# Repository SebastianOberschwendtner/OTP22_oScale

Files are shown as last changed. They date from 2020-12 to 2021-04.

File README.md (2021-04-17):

Card
# OTP22_oScale







Open Source Scale for Brewing Espresso.

>More information can be found in the *beautiful* [wiki](https://github.com/knuffel-v2/OTP22_oScale/wiki/home).

>:construction: The **schematic** and **PCB** are designed with *CircuitMaker*. The project can be found [here](https://circuitmaker.com/Projects/Details/SebastianOberschwendtner/OTP-22oScale).

## Software Framework







## Branches
|Name|Status|Description|
|---|---|---|
|**main**|`active`| Main branch for developing with VSCode|
|**unittest**|`stale`| Branch to test unit test framework and github actions.|
 
## Technical Data

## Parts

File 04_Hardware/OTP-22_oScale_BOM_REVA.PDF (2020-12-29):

Designator | Comment | Quantity
C1, C2, C3, C4 | 22 pF | 4
C5, C6, C9, C10, C11, C12 | 100 nF | 6
C7 | 100 µF | 1
C8, C14, C16 | 1.0 µF | 3
C13, C15 | 2.2 µF | 2
D1 | 1N4148 | 1
J1 | Battery Connector | 1
K1 | Display | 1
K2 | Programming Port | 1
Q1, Q3 | IRLML2502 | 2
Q2 | IRLML6401 | 1
R1, R12, R17, R19 | 22 kO | 4
R2, R16, R20 | 4.7 kO | 3
R3, R4 | 32 kO | 2
R5, R6, R7, R18, R21, R24 | 1 kO | 6
R8, R9, R10 | 100 kO | 3
R11 | 180 O | 1
R13, R14, R25 | 10 kO | 3
R15 | 100 O | 1
R22 | 57 O | 1
R23 | Offset | 1
SW1, SW2, SW3, SW4 | 430186050716 | 4
U1 | ATmega8L-8PU | 1
U2, U3 | LT1013D | 2
U4 | Texas Instruments ADS7822P | 1
U5 | AD580SH | 1
U6 | LF33CDT-TR | 1
U7 | LM7805 | 1
X1 | 8.0 MHz | 1
X2 | Load Cell Connector | 1

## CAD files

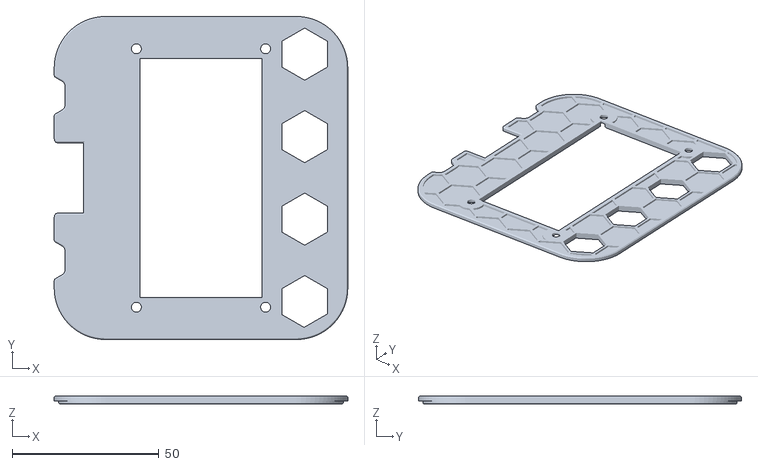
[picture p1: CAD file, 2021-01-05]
04_Hardware/OTP-22_Case_Top_v002.stl
100.0 x 110.0 x 2.80

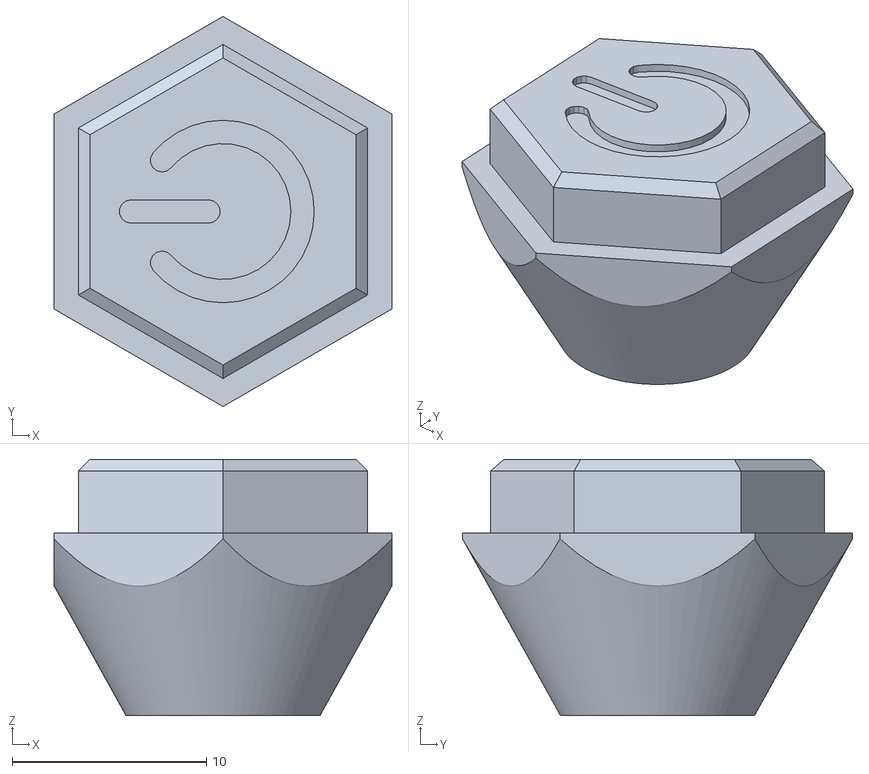
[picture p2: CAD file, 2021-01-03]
04_Hardware/OTP-22_Key_0_v002.stl
17.4 x 20.1 x 13.2

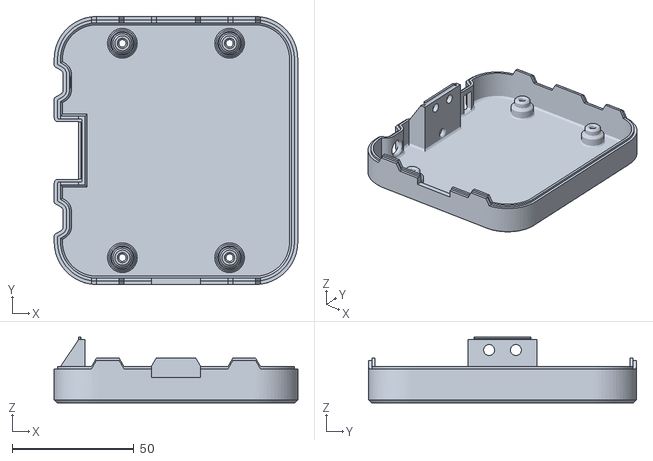
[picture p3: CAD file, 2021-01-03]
04_Hardware/OTP-22_Case_Bottom_v001.stl
100.0 x 110.0 x 26.9

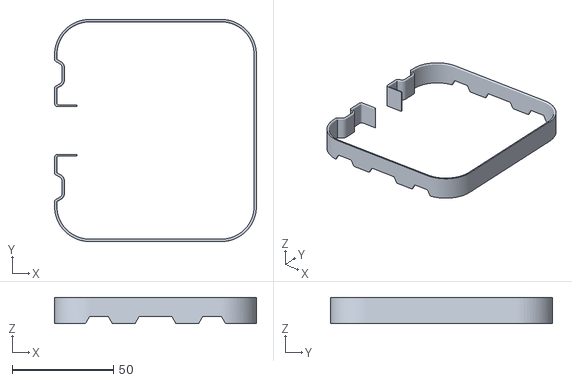
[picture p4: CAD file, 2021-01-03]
04_Hardware/OTP-22_Case_TopFrame_v001.stl
100.0 x 110.0 x 12.9

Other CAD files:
04_Hardware/OTP-22_Key_2_v001.stl
04_Hardware/OTP-22_Key_1_v001.stl
04_Hardware/OTP-22_Key_3_v001.stl
04_Hardware/OTP-22_Case_Top_v001.stl
04_Hardware/OTP-22_Key_0_v001.stl

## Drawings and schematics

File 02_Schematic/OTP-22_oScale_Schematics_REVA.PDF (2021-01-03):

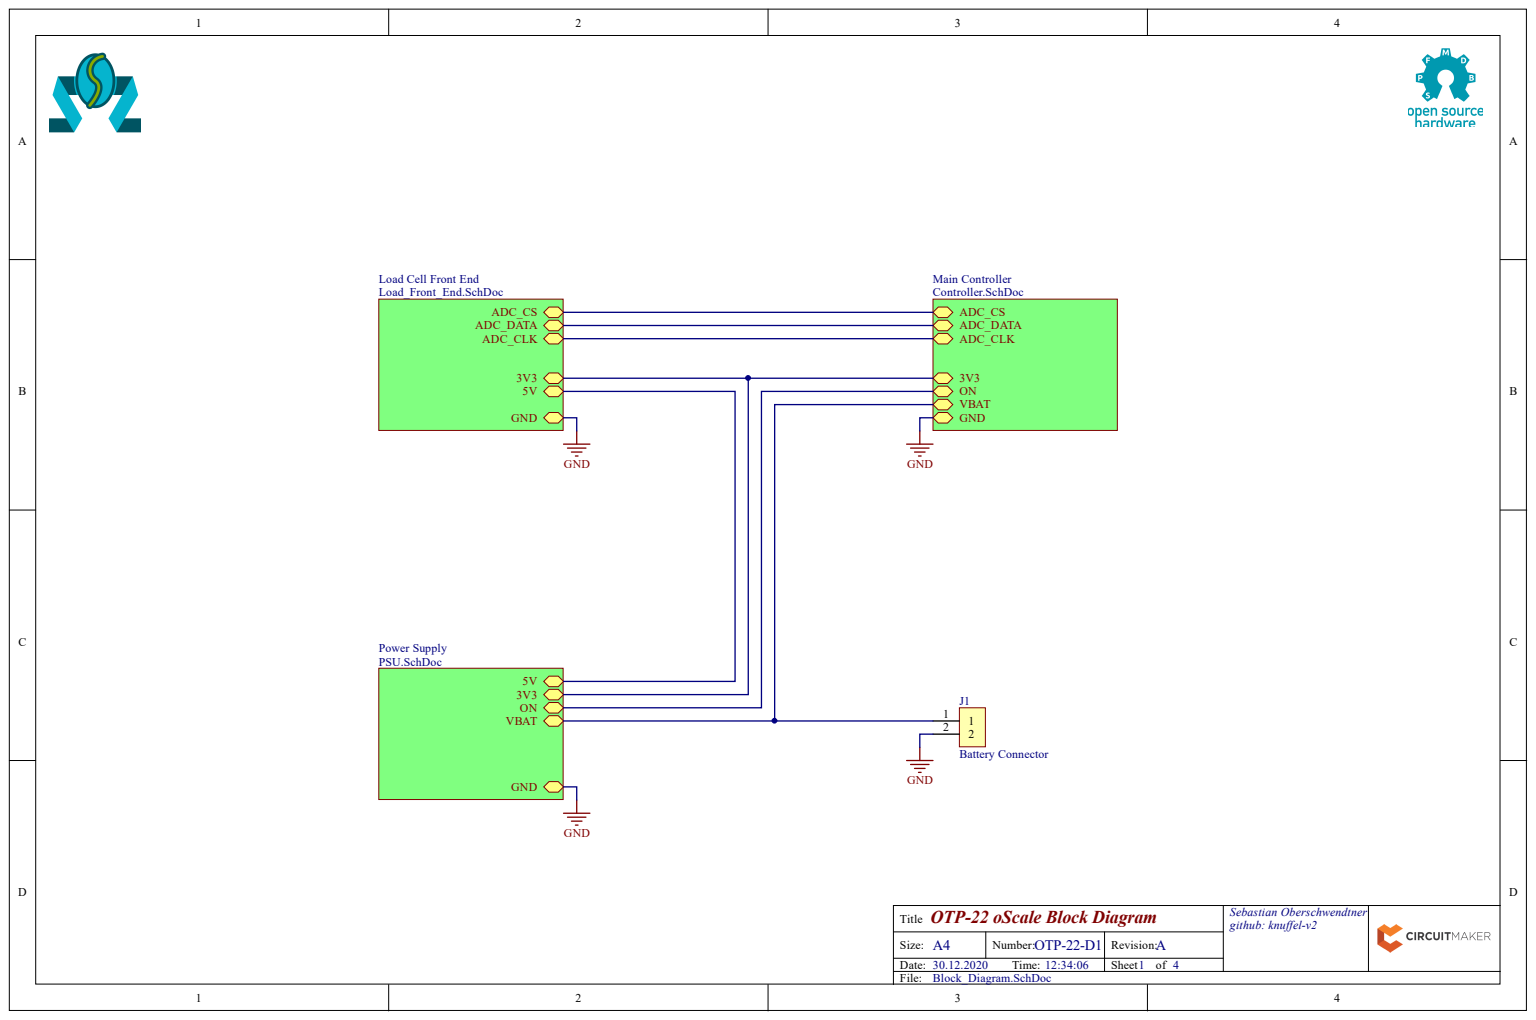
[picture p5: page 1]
Main Controller; Power Supply; Battery Connector

Load Cell Front End
Load_Front_End.SchDoc

OTP-22 oScale Block Diagram Title | Sebastian Oberschwendtner github: knuffel-v2

Size: A4 | Number: OTP-22-D1 | Revision: A
Date: 30.12.2020 Time: 12:34:06 | | Sheet of

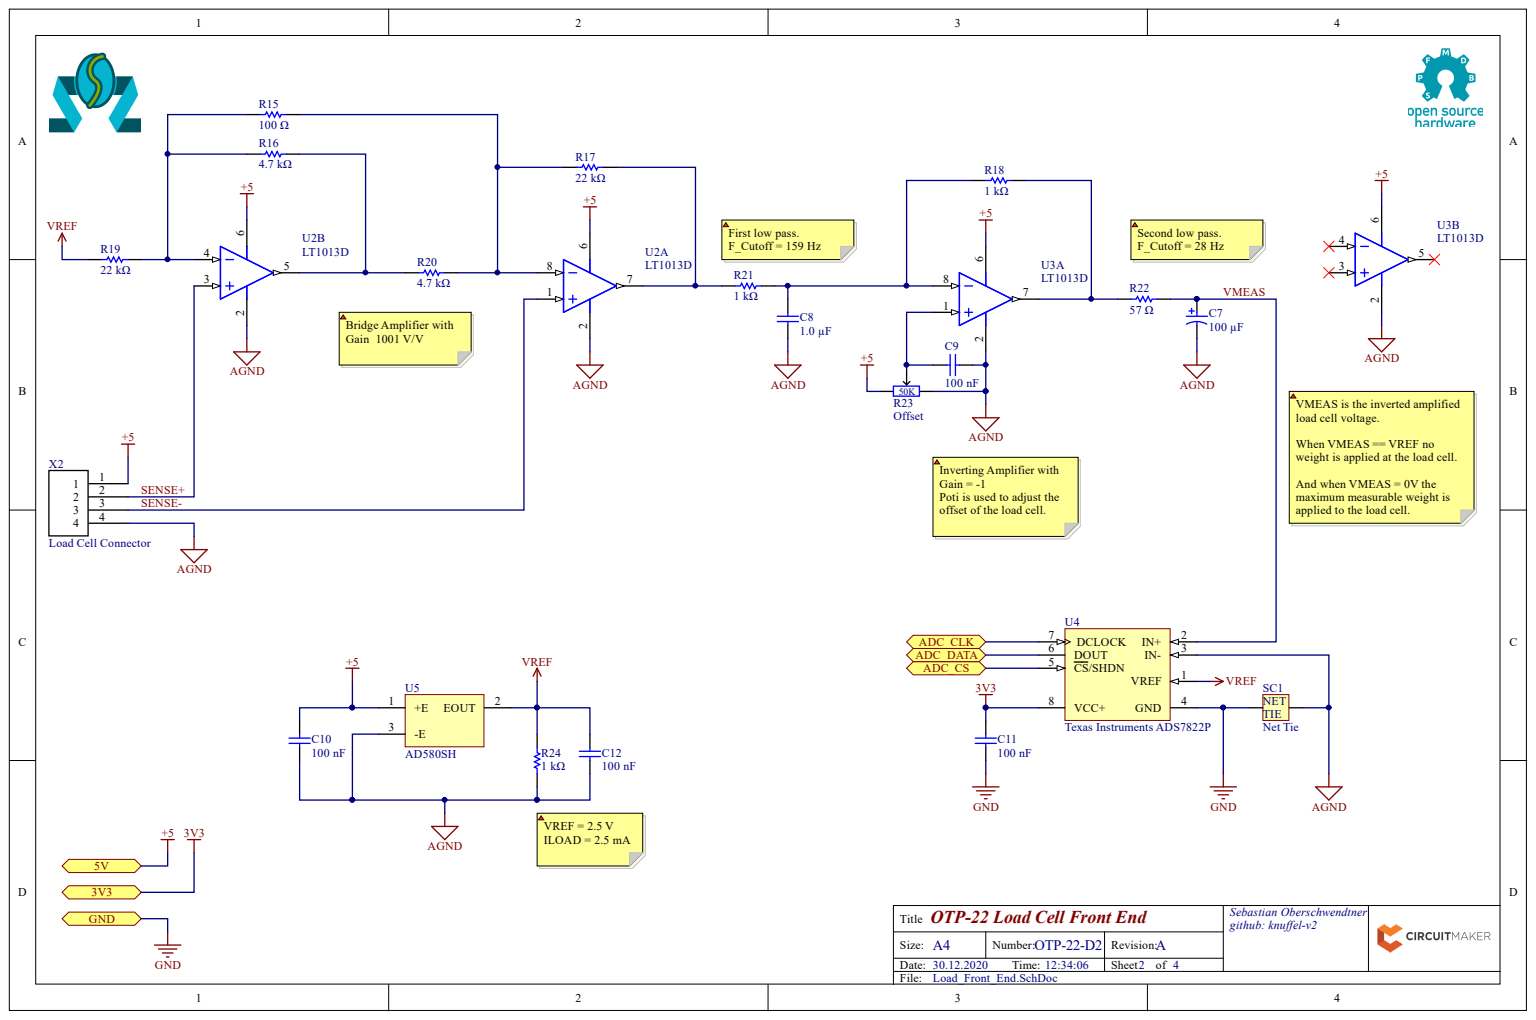
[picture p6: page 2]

VMEAS is the inverted amplified
load cell voltage.

When VMEAS == VREF no
weight is applied at the load cell.

Inverting Amplifier with
Gain = -1
Poti is used to adjust the
offset of the load cell.

And when VMEAS = 0V the
maximum measurable weight is
applied to the load cell.

OTP-22 Load Cell Front End Title | Sebastian Oberschwendtner github: knuffel-v2

Size: A4 | Number: OTP-22-D2 | Revision: A

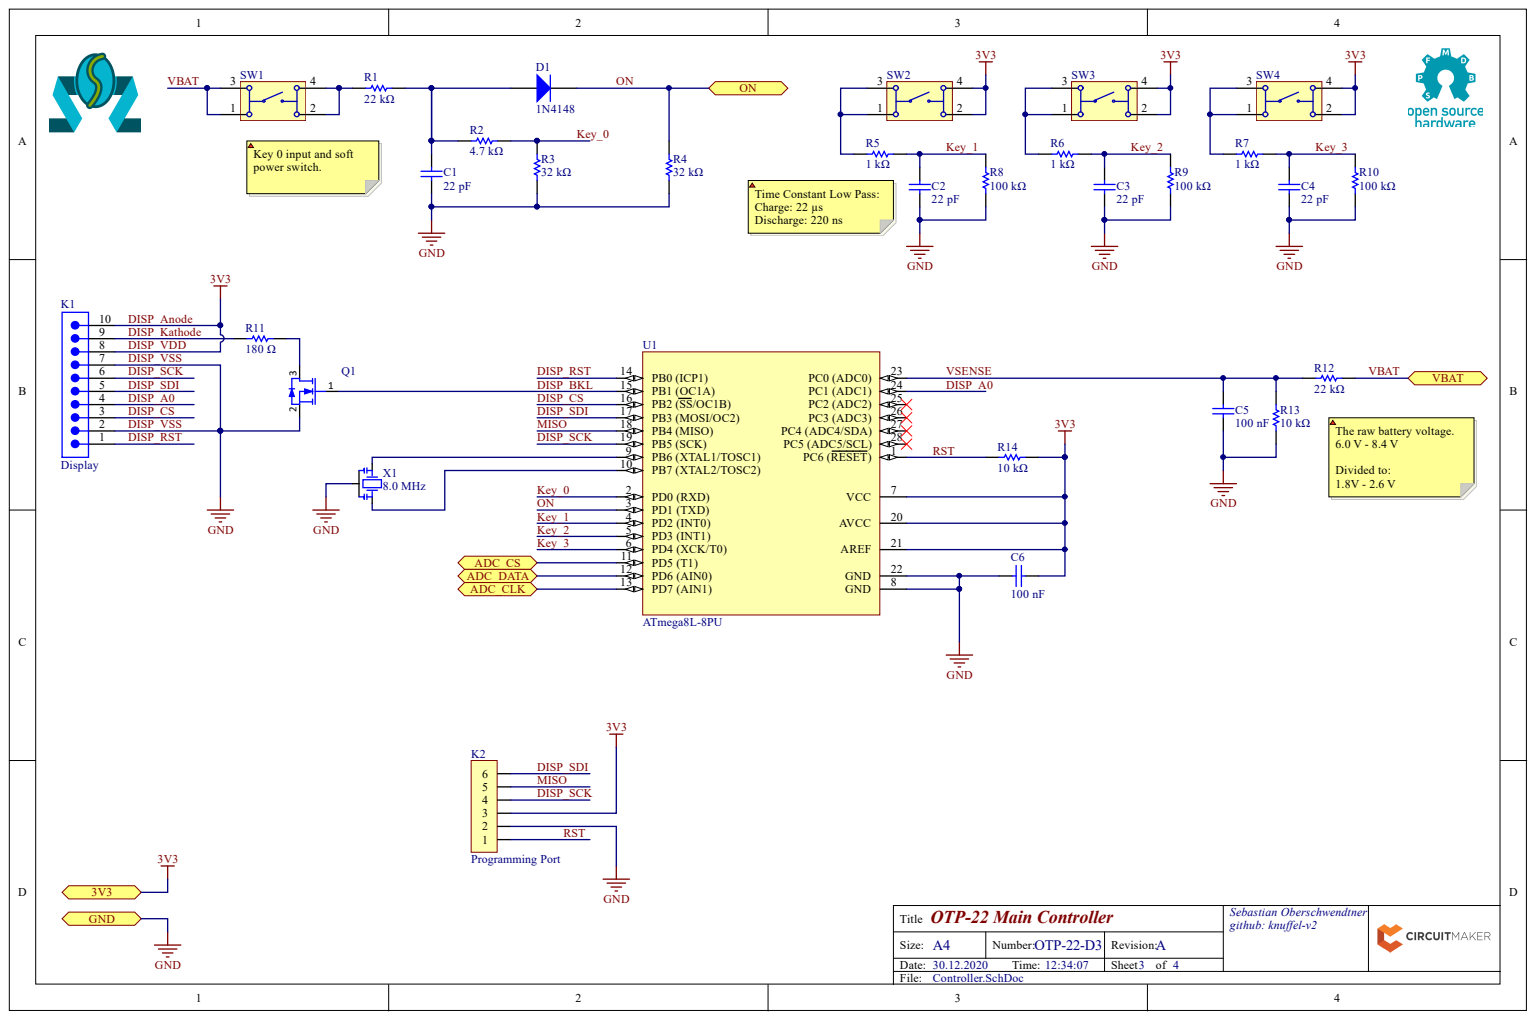
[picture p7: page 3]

Key 0 input and soft
power switch.

Time Constant Low Pass:
Charge: 22 µs
Discharge: 220 ns

The raw battery voltage.

X1 Key_0 | PD0 (RXD) 2

PB7 (XTAL2/TOSC2) 10

OTP-22 Main Controller Title | Sebastian Oberschwendtner github: knuffel-v2

Size: A4 | Number: OTP-22-D3 | Revision: A

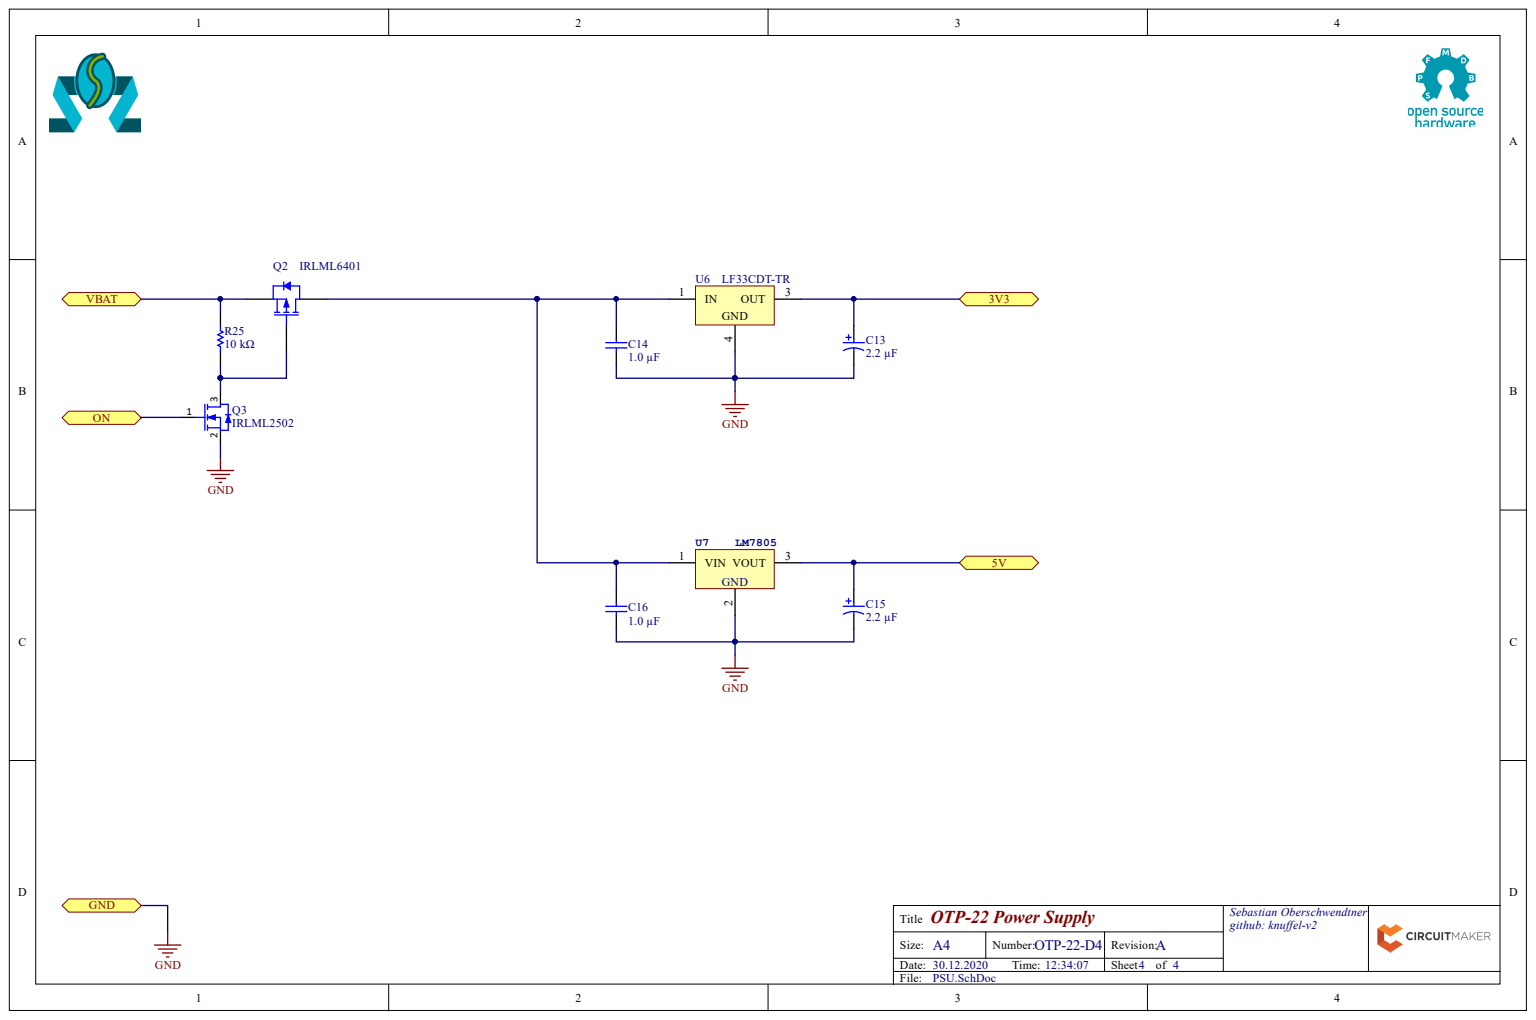
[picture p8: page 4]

OTP-22 Power Supply Title | Sebastian Oberschwendtner github: knuffel-v2

Size: A4 | Number: OTP-22-D4 | Revision: A

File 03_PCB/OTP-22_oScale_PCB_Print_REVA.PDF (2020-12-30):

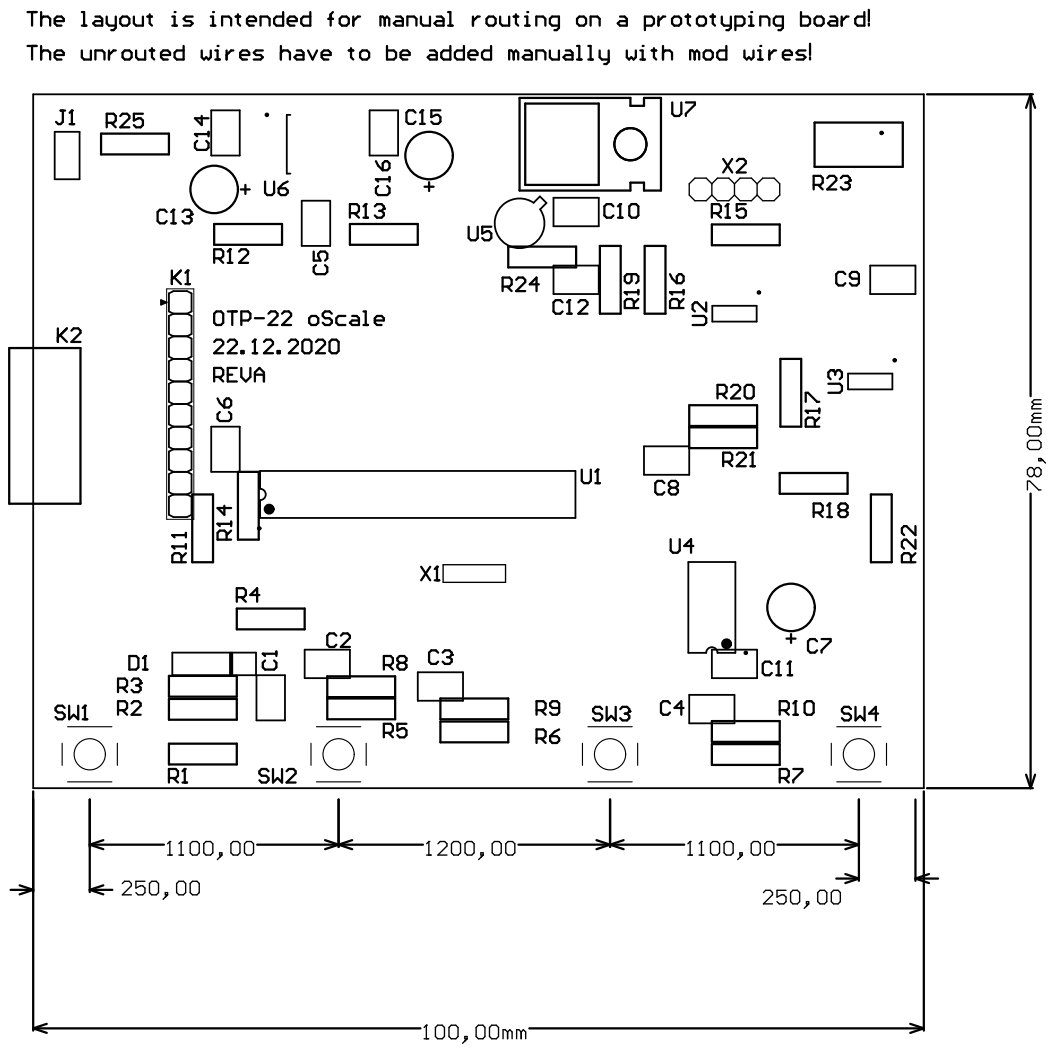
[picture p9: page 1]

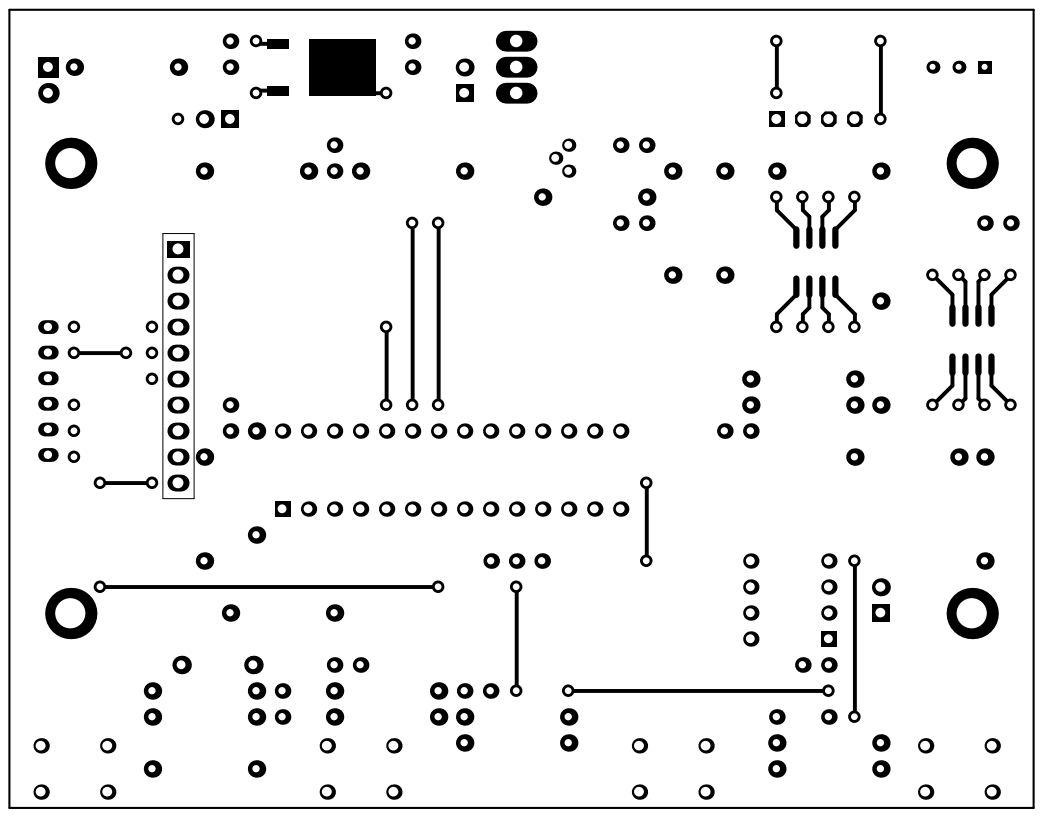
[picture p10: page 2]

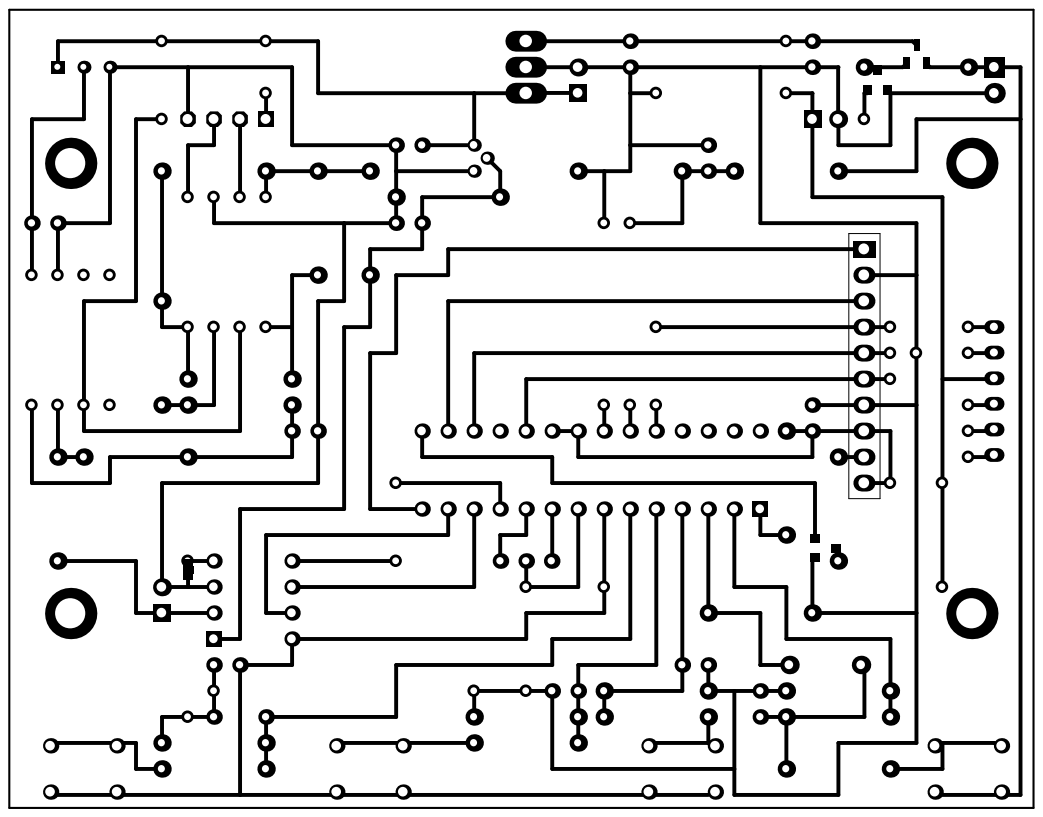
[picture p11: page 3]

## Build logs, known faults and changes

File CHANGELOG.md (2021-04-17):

# Changelog for OTP-22 oScale

## [V2.0.0](https://github.com/knuffel-v2/OTP22_oScale/releases/tag/v2.0.0) *(2021-xx-xx)*

>Released by `SO`

### Release Notes:
- [V1.1.0](https://github.com/knuffel-v2/OTP22_oScale/releases/tag/v1.1.0): 
    - Fixed Timing Issue (#9)
    - After the update of *platformio*, the inline functions have to be inserted in the header files as well, otherwise the compiler complains. :shrug:
    - Adds IIR filters to *filter8*. Available filters: **PT1**.
    - The timer is now initialized with zero.
    - Addes unit tests for: *scheduler*, *sarb*

### Fixed Issues:

- #9: Timer too slow

## [V1.0.0](https://github.com/knuffel-v2/OTP22_oScale/releases/tag/v1.0.0) *(2021-01-06)*

>Released by `SO`

### Release Notes:
- Initial release of the firmware for **oScale**.
- Manual mode works and measures the weight and implements a basic timer.
- There are a few functions open, but the basic functionality is given and it is a good starting point for further releases. **Stay tuned!**

### Fixed Issues:

- n/a

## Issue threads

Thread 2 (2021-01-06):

Improve the Filter for the ADC Data

knuffel-v2, 2021-01-06:
# Current Behavior:
The current filter is simple PT1 filter with a time constant of *0.5s*.

# Expected Behavior:
The filter should be improved to settle faster and also give the derivative of the weight measurement to get the flow rate.
Use the same filter as used in [OTP-15 oVaro]( https://github.com/knuffel-v2/OTP15_oVario).

knuffel-v2, 2021-03-15:
This issue is split in two tasks:
- [ ] Implement generic IIR filters in *filter8*.
- [ ] Add a optimized filter type to the scale and test it.

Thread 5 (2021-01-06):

Finish Initial Documentation

knuffel-v2, 2021-01-06:
The documentation for the following topics has to be done:
- Hardware:
    - Schematic
    - Building the PCB
    - Assembling the Case
- Software
    - Activity Diagrams
    - State Machine
    - Timing

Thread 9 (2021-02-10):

Timer too slow

knuffel-v2, 2021-02-10:
# Current Behavior
The timer of the scale counts too slow.

# Expected Behavior
The timer should count in *1s* intervall.

# Fix
The system task has to wait one systick less to increment the counter value.

Closed 2021-02-10.

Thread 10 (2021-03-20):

Shutdown not reliable

SebastianOberschwendtner, 2021-03-20:
# :bug: Bug
When pressing the shutdown button not long enough the scale locks up. You have to press it longer than a short moment, though. 🤷
When the button is pressed long enough the shutdown works.

Closed 2022-05-22.

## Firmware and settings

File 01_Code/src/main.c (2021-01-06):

/**
 * OTP-22 oScale Firmware
 * Copyright (c) 2020 Sebastian Oberschwendtner, sebastian.oberschwendtner@gmail.com
 *
 *
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
 */
/**
 ******************************************************************************
 * @file    main.c
 * @author  SO
 * @version V1.0.0
 * @date    21-November-2020
 * @brief   Main firmware of the oScale.
 ******************************************************************************
 */
// ****** Includes ******
#include "oScale.h"

// ****** Variables ******
volatile unsigned char TickPassed = 0;

// ****** Main ******
int main(void)
{
  //Initialize system
  scale_InitTask();
  scale_InitSysTick();

  // Initialize tasks
  disp_InitTask(TASK0_us);
  gui_InitTask();
  adc_InitTask();

  // Schedule tasks
  scheduler_init(SYSTICK_us);
  schedule_us(TASK0, TASK0_us);
  schedule_ms(TASK1, TASK1_ms);
  schedule_ms(TASK2, TASK2_ms);

  // Start SysTick Timer
  sei();
  scale_StartSysTick();

  while (1)
  {
    if (TickPassed)
    {
      TickPassed = 0;
      // ****** TASK0 (5 kHz) ******
      if (run(TASK0))
      {
        Task_Disp();
        Task_GUI();
      }

      // ****** TASK1 (100 Hz) ******
      if (run(TASK1))
      {
        Task_ADC();
      }

      // ****** TASK2 (5 Hz) ******
      if (run(TASK2))
      {
        Task_SYS();
      }
    }

    // ****** free-running ******
  }
  return 0;
};

//****** Interrupts ******
/**
 * @brief SysTick interrupt for Systick variable.
 * @details Interrupt-handler
 */
ISR(TIMER0_COMPA_vect)
{
  TickPassed = 1;
  run_scheduler();
};

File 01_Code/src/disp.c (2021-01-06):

/**
 * OTP-22 oScale Firmware
 * Copyright (c) 2020 Sebastian Oberschwendtner, sebastian.oberschwendtner@gmail.com
 *
 *
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
 */
/**
 ******************************************************************************
 * @file    disp.c
 * @author  SO
 * @version V1.0.0
 * @date    21-November-2020
 * @brief   Display controller for the scale. Tries to minimize RAM usage.
 ******************************************************************************
 */
// ****** Includes ******
#include "disp.h"
#include "font.h"
#include "digit.h"

// ****** Variables ******
task_t taskDisp;    // Task data for display
dispDat_t datDisp;  // Content data for display


// ****** Functions ******
/**
 * @brief Set the A0 pin high. Indicating that data is sent.
 * @details inline function.
 */ 
inline void disp_SetA0High(void)
{
    PORT_A0 |= (1<<DISP_A0);
};

/**
 * @brief Set the A0 pin low. Indicating that a command is sent.
 * @details inline function.
 */ 
inline void disp_SetA0Low(void)
{
    PORT_A0 &= ~(1<<DISP_A0);
};

/**
 * @brief Set the CS pin high.
 * @details inline function.
 */ 
inline void disp_SetCSHigh(void)
{
    PORTDISP |= (1<<DISP_CS);
};

/**
 * @brief Set the CS pin low.
 * @details inline function.
 */ 
inline void disp_SetCSLow(void)
{
    PORTDISP &= ~(1<<DISP_CS);
};

/**
 * @brief Set the RST pin high. Disabling the reset of the display.
 * @details inline function.
 */ 
inline void disp_SetRSTHigh(void)
{
    PORTDISP |= (1<<DISP_RST);
};

/**
 * @brief Set the RST pin low. Enabling the reset of the display.
 * @details inline function.
 */ 
inline void disp_SetRSTLow(void)
{
    PORTDISP &= ~(1<<DISP_RST);
};

/**
 **********************************************************
 * @brief TASK DISP
 **********************************************************
 * The display task, which handles the display.
 * 
 **********************************************************
 * @details
 * @Execution:	Non-interruptable
 **********************************************************
 */
void Task_Disp(void)
{
    // Switch for active command
    switch (taskDisp.command)
    {
    case DISP_CMD_INIT:
        disp_Init();
        break;
    
    case DISP_CMD_CLEAR:
        disp_Clear();
        break;

    case DISP_CMD_LINE_H:
        disp_WriteHorizontalLine();
        break;

    case DISP_CMD_LINE_V:
        disp_WriteVerticalLine();
        break;

    case DISP_CMD_WRITE_CHAR:
        disp_WriteChar();
        break;

    case DISP_CMD_WRITE_DIGIT:
        disp_WriteDigit();
        break;

    case DISP_CMD_WRITE_STRING:
        disp_WriteString();
        break;

    case DISP_CMD_WRITE_NUMBER:
        disp_WriteNumber();
        break;

    default:
        break;
    }
};

/**
 * @brief Initialize the task data of the display.
 * @param us_per_tick The schedule of the task as set in the scheduler.
 */
void disp_InitTask(unsigned int us_per_tick)
{
    // Task struct
    sarb_InitStruct(&taskDisp);
    taskDisp.command = DISP_CMD_INIT;
    taskDisp.schedule = us_per_tick;

    // Display data
    datDisp.x = 8;
    datDisp.y = 0;
};

/**
 * @brief Initialize the display driver peripherals.
 */
void disp_Init(void)
{
    // Switch for active command sequence
    switch (taskDisp.sequence)
    {
    case 0:
        // Initialize the I/Os
        DDRDISP = 0xFF; //All Pin are outputs
        DDR_A0 |= (1<<DISP_A0); // DISP_A0 is also an output
        disp_SetCSHigh();
        disp_SetRSTLow();

        // Initialize the SPI
        SPCR = (1 << SPE) | (1 << MSTR) | (1 << CPOL) | (1 << CPHA) | (1 << SPR0);

        // Set wait for 1 ms before continuing with the task
        taskDisp.wait = 1000 / taskDisp.schedule;
        taskDisp.sequence++;

        //Disable the display reset
        disp_SetRSTHigh();
        break;

    case 1:
        //Decrease wait counter until wait is over
        if (taskDisp.wait)
            taskDisp.wait--;
        else
            taskDisp.sequence++;
        break;

    case 2:
        disp_SetCSLow();
        // Set the display start line to 0
        SPDR = DISP_CTRL_START;
        taskDisp.sequence++;
        break;

    case 3:
        // Set ADC reverse
        if (disp_SendCommand(DISP_CTRL_ADC_SEL + 0))
            taskDisp.sequence++;
        break;

    case 4:
        // Set normal COM output
        if (disp_SendCommand(DISP_CTRL_COM_OUT))
            taskDisp.sequence++;
        break;

    case 5:
        // Normal Display
        if (disp_SendCommand(DISP_CTRL_REVERSE))
            taskDisp.sequence++;
        break;

    case 6:
        // Set bias to 1/9
        if (disp_SendCommand(DISP_CTRL_BIAS))
            taskDisp.sequence++;
        break;

    case 7:
        // Set booster, regulator and follower on
        if (disp_SendCommand(DISP_CTRL_PWR | 0b111))
            taskDisp.sequence++;
        break;

    case 8:
        // Set internal booster to 4x
        if (disp_SendCommand(DISP_CTRL_BOOST))
            taskDisp.sequence++;
        break;

    case 9:
        // continue set boost
        if (disp_SendCommand(0x00))
            taskDisp.sequence++;
        break;

    case 10:
        // Set the contrast
        if (disp_SendCommand(DISP_CTRL_VOLT | 0b111))
            taskDisp.sequence++;
        break;

    case 11:
        // Continue contrast setting
        if (disp_SendCommand(DISP_CTRL_VOLUME))
            taskDisp.sequence++;
        break;

    case 12:
        // finish contrast setting
        if (disp_SendCommand(0x05))
            taskDisp.sequence++;
        break;

    case 13:
        // Set the static indicator off
        if (disp_SendCommand(DISP_CTRL_INDICATOR))
            taskDisp.sequence++;
        break;

    case 14:
        // Continue static indicator setting
        if (disp_SendCommand(0x00))
            taskDisp.sequence++;
        break;

    case 15:
        // Enable display
        if (disp_SendCommand(DISP_CTRL_ON + 1))
            taskDisp.sequence++;
        break;

    case 16:
        // Exit the command
        taskDisp.command = DISP_CMD_CLEAR;
        taskDisp.sequence = 0;

    default:
        break;
    }
};

/**
 * @brief Send a byte to the display.
 * @param data The data for the display.
 * @return Returns one when the data was written to the data register of the SPI.
 */
unsigned char disp_SendByte(unsigned char data)
{
    // Only send data, when SPI is not busy
    if (SPSR & (1<<SPIF))
    {
        SPDR = data;
        return 1;
    }
    else
        return 0;
};

/**
 * @brief Send a command byte to the display without payload.
 * @param command The command for the display.
 * @return Returns one when the command was written to the data register of the SPI.
 */
unsigned char disp_SendCommand(unsigned char command)
{
    disp_SetA0Low();
    return disp_SendByte(command);
};
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

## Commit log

2020-12-16 :memo: Bugfix in readme header picture.
    [OTP-22_Case_MainHousing_v000.stl]
2020-12-17 :wrench: Added empty folder structure.
    [OTP-22_Case_MainHousing_v000.stl]
2020-12-19 :wrench: Adjusted file.
    [OTP-22_Case_MainHousing_v000.stl]
2020-12-22 :memo: Documentation for REVA hardware.
    [OTP-22_oScale_BOM_REVA.csv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]
2020-12-22 :memo: Added bottom layer print with grid.
2020-12-22 :memo: Renamed bottom layer print with grid.
2020-12-29 :wrench: Changed the dividier network for the power switch.
    [OTP-22_oScale_BOM_REVA.csv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]
2020-12-30 :wrench: Changed the pinout of DISP_A0.
    [oScale_Board_REVA.GBL, oScale_Board_REVA.GBO, oScale_Board_REVA.GBP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]
2021-01-03 Final PCB and hardware revision. Code is in progress...
    [OTP-22_Case_Bottom_v001.stl, OTP-22_Case_MainHousing_v000.stl, OTP-22_Case_TopFrame_v001.stl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]
2021-01-05 Finished hardware and worked on manual state.
    [OTP-22_Case_Top_v002.stl]
2021-02-10 :bug: Fixes #9: Timer too slow.
    [oScale.c, oScale.h]
2021-03-05 :hourglass: Worked on filter implementation.
2021-03-11 :art: Adds simple python simulation for filters.
    The simulation captures the discrete integer behavior as
    implemented in the AVR. It is used to investigate the influence
    of rounding errors and coefficient scaling.
2021-03-14 :tada: Finished Filter Simulation
    The filter simulation can be used to investigate the influence of
    the coefficient scaling on the filter behavior. You can plot several
    filters of the same kind with different scaling parameters and compare
    them.
2021-03-15 :art: Adds IIR filters to *filter8*.
    This is the base to further work on #2. Currently, only a PT1 filter can
    be used, but based on its implementation more filters will be added and
    tested. You can use the python simulation to see the effect of different
    filter types and their parameters.
2021-03-15 :wrench: The timer initializes with zero seconds.
2022-05-22 :bug: Fixes bug in shutdown state. Fixes #10.
    The actual problem was the large capacitor of the 3.3V rail. The
    microcontroller could restart sometime because of the left over charge.
    The smaller capacitance of 2.2 uF should resolve this now.
    [oScale.c, oScale.h]

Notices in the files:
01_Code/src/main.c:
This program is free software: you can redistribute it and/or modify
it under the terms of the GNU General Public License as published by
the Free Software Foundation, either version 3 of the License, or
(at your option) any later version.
